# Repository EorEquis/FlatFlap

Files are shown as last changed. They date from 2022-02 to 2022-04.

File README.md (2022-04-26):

## What 
	A "Cover/Calibrator".  Features a motorized telescope cover, and optional calibrator 
	(light/led/EL panel) controller.

## Who
	Created By:  eorequis@stuffupthere.com

## When
	Last modified:  2022-02-11

## Current State
	V2 Arduino Firmware
		The basic syntax of the serial connection protocol is :
		c00n# : c = command ([P]ing, [C]over, [L]ight) and n is typically a value mapped to ASCOM enums
		for cover and calibrator.
		
		List of common commands:
		P000#
		Ping to check if board is connected. Returns P999* when successful.
		
		C001#
		Close the cover. Returns C020* if closing, and C011* if already closed.
		
		C003#
		Open the cover. Returns C020* if opening, and C031* if already opened.
		
		L001#
		Turn off light. Returns L010* if it switch off, and L011* if already off.
		S001* or S003* means the light is not configured.
		
		L003#
		Turn On light. Returns L030* if it switched on, and L031* if already on.
		S001* or S003* means the light is not configured.
		
		S000#
		Check staus. Returns S0[light status][cover status]*
		Light status can be 0 (not configured), 1 (off), or 3 (on).
		Cover status can be 1 (closed), 2 (moving), or 3 (open).
		Any other numbers indicate an error.
		
	ASCOM Driver Options. Use only one, you cannot connect to both at the same time. Only CoverCalibrator can
	control both the cover and light.
	
	ASCOM Switch Driver updated to V2 protocol 
		The ASCOM.ScopeCover.Switch can function as a switch driver to control only the cover.  Useful
		if you don't want/need the complexity of a calibration light, and also allows greater flexibility 
		with various clients/sequencing strategies.
		
		Download ScopeCover Setup.exe to install this driver.
	
	ASCOM CoverCalibrator Driver
		The ASCOM.FlatFlap.CoverCalibrator driver can be used with either a cover only (the light 
		functionality will still present in the client, but will do nothing) or with some sort of 
		switchable light source.  (My own device is a small EL sheet and 12V DC inverter, 
		controlled by a small relay). 
		
		Download FlatFlap Setup.exe to install this driver.
	
## Tested With
	Servos: 
		HiTec HS-635HB - https://servodatabase.com/servo/hitec/hs-635hb
		Aero Sport CS-28R - They're so old there is no URL.
		SG-90 Micro Servos.  There's dozens of various brands with the same model number.  Any should work.
			
	Arduino Boards:
		Gikfun Arduino Nano Clone - https://www.amazon.com/gp/product/B00SGMEH7G
		Arduino Uno - https://www.amazon.com/gp/product/B008GRTSV6/
		ELEGOO UNO R3 Board - https://www.amazon.com/ELEGOO-Board-ATmega328P-ATMEGA16U2-Compliant/dp/B01EWOE0UU
		ELEGOO MEGA R3 Clone - https://www.amazon.com/gp/product/B01H4ZLZLQ/
		Some Uno clone I can't even find a name of or link to.
	
	Relays:
		ARCELI KY-019 5V One Channel Relay - https://www.amazon.com/gp/product/B07BVXT1ZK/
		
	Calibrator Lights
		Adafruit EL Panel - https://www.adafruit.com/product/625 
		Adafruit 12V EL inverter - https://www.adafruit.com/product/448
		
	Software:
		Sequence Generator Pro 
			4.0.0.700 64 Bit
			4.1.0.741 64 Bit
		N.I.N.A 
			V2.0 BETA 019 
			V2.0 BETA 045
			V2.0 BETA 049
			V2.0 RC001

## Usage Notes
	V2 Arduino Firmware configuration
		Compile and upload the firmware with the Arduino IDE. Make sure to choose
		the correct board, processor, and port under the "Tools" menu. Everything
		you need to change is in "Config.h"
		
		DEBUG cannot be used with the ASCOM driver. It gives aditional responses
		in the serial monitor, that the driver cannot understand.
		
		SERVOREVERSE is needed if the cover closes when you try to open it and vice
		versa. You may have to switch the closedPos and openPos values, since this
		option only changes direction.
		
		RELAYLOW is needed if the light turns on when you try to turn it off and
		vice versa.
		
		CALIBRATOR needs to be defined if you are using a light panel. Comment it
		out if you only want to use the scope cover.
		
		closedPos may need to be adjusted to keep from trying to force the servo
		past the fully closed position. If the servo makes noise when closed,
		adjust until it is sealed but quiet.
		
		openPos can be adjusted if you want the cover to open a different amount.
		
		servoPin can be changed if you want to use a differnt pin for the servo.
		
		lightPin can be changed if you want to use a different pin for the relay.
		
		servodelay controls the speed the servo moves.
	
	Arduino resets on serial connection. (Ignore if using ScopeCover only)
		The ASCOM driver code by default is compiled with a 2000ms wait when
		connecting. This will give the Arduino time to reset before use.
		
		Optionally, you can stop it from resetting by adding a 10uf capacitor to
		the arduino between GND and RST. You can then remove the wait(2000) line
		in the Connected(Set) from the ASCOM driver code, recompile and resintall
		the driver.
		
	SGP Switch Handling
		Sequence Generator Pro (As of v4 anyway) handles switches...strangely.  
		After initial install, the first time you run SGP, it will claim to 
		find and connect to the switch, but probably won't actually connect.  
		(Unless your arduino is COM1...unlikely)
		
		To "solve" this either go to SGP's Switches tab in SGP Control Panel, and 
		change the switch's setting to reflect the correct COM Port, then stop and 
		restart SGP.

		OR
		
		Before launching SGP, open any other client program that doesn't try to 
		auto-connect every switch driver on your system, and configure the ScopeCover 
		switch to the correct COM port before connecting to it.  Disconnect and exit 
		gracefully, and the setting will be retained in the device profile.
		
		OR
		
		Before running SGP after switch installation, launch ASCOM Profile Explorer, 
		find "ASCOM.ScopeCover.Switch" in the "Switch Drivers" section on the left.  
		Click "ASCOM.ScopeCover.Switch", and then in the right pane, add a new Value
		called "COM Port" (Note the space) with Data of "COMn" (Note the lack of a 
		space) where n is your device's com port.


		
		You should also note : If you install the Switch Driver, and later the CC 
		driver, using the same arduino, SGP will retain the previous switch driver's 
		config, and auto-connect to that COM port, thus causing connection attempts to 
		the new CC driver to fail, Access to COM Port Denied.

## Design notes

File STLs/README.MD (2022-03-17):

## Servo Mounts
	Each servo mount is named "Mount Type NNNmm".
	Type = Type of servo.  Standard, Micro, etc.
	NNNmm = The approximate DIAMETER of the arc the "feet" sit on.  Select or modify 
		(And share if you do!) the mount with the correct servo type and OUTER diameter
		of your scope tube.

## Scope Caps
	The one-piece "Full Scope Cover" comes from the original Thing at 
		https://www.thingiverse.com/thing:2307397. It has a diameter of approximately 
		115mm.  It can be resized as needed, but bear in mind that rescaling will
		also rescale the servo mount hole.
	The two-piece, "arm" and "lid" are a simpler design requiring no supports, but 
		they do need to be glued together. It has a diameter of approximately 100mm, 
		and should be considerably easier to resize. Just remember to adjust the 
		width of the slot appropriately.
		
## Enclosures
	Nano Enclosure is a modified version of https://www.thingiverse.com/thing:5238660
		The indent for the USB plug has been made deeper for more secure connections,
		and the lid	tweaked for a slightly better fit.

## CAD Files
	Where I have them, I have uploaded SketchUp files, created in Sketchup Make 2017.
	
	If you modify/create your own files for use on a particular scope/lens/etc, please
	share whatever STLs and/or CAD files you have. :)

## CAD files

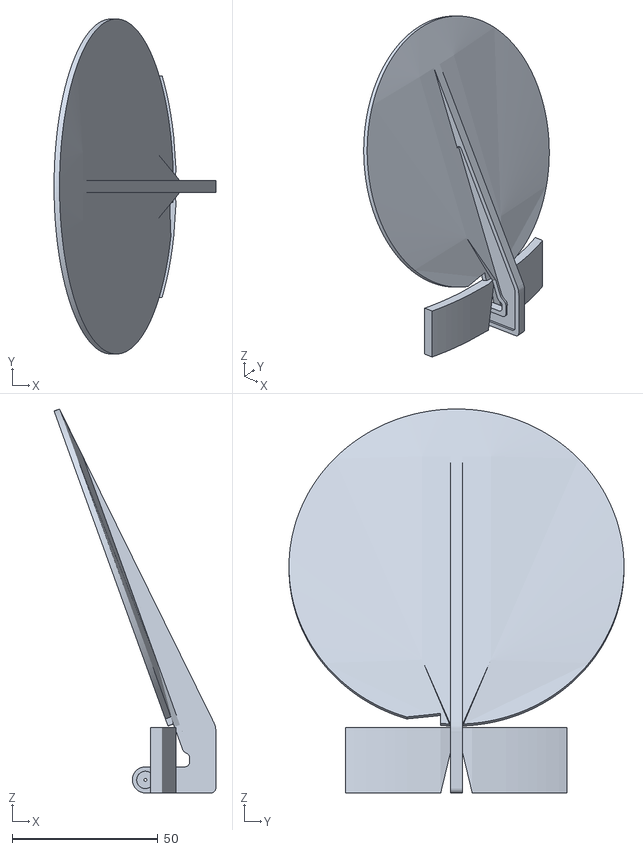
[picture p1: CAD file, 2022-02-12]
STLs/Full ScopeCover-Supported.stl
55.6 x 115.0 x 131.8

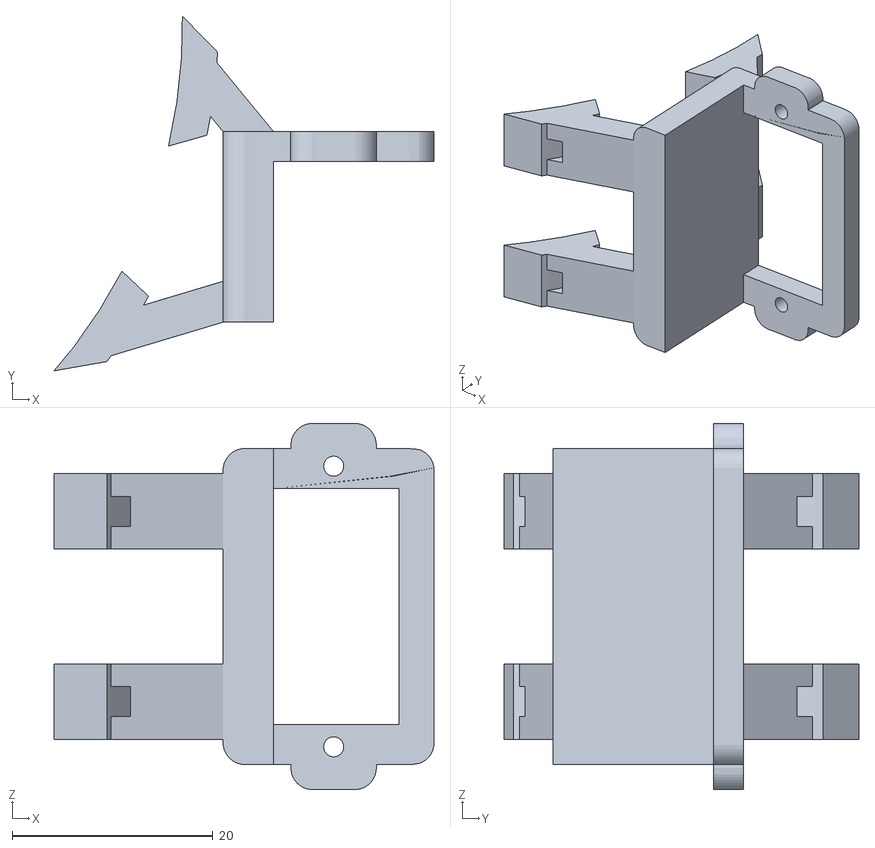
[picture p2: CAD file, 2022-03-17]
STLs/Mount Micro Servo 110mm.stl
37.9 x 35.3 x 36.5

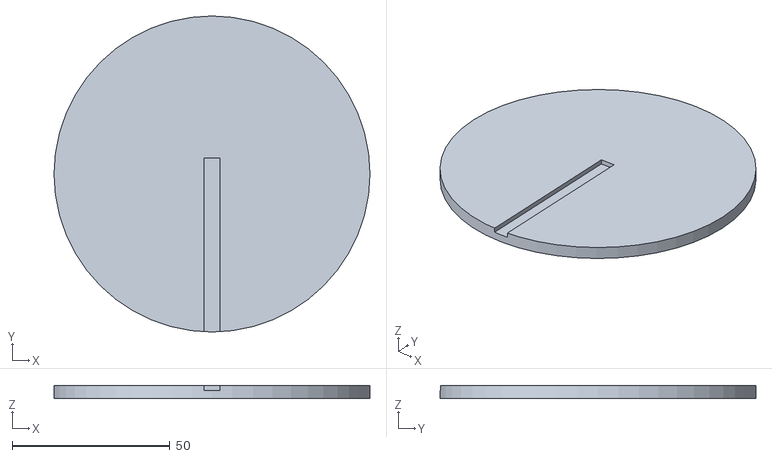
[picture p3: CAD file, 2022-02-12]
STLs/Lidv2.stl
100.0 x 100.0 x 4.00

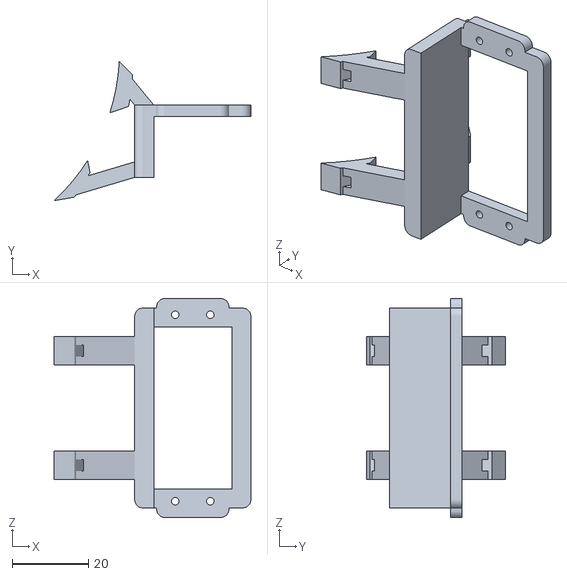
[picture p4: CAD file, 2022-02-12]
STLs/Mount Std Servo 100mm.stl
51.7 x 36.6 x 57.5

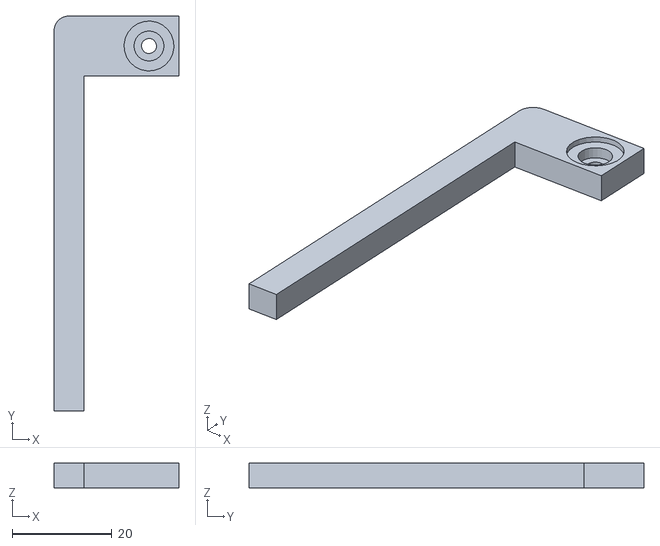
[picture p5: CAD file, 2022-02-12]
STLs/Armv2.stl
25.0 x 79.0 x 5.00

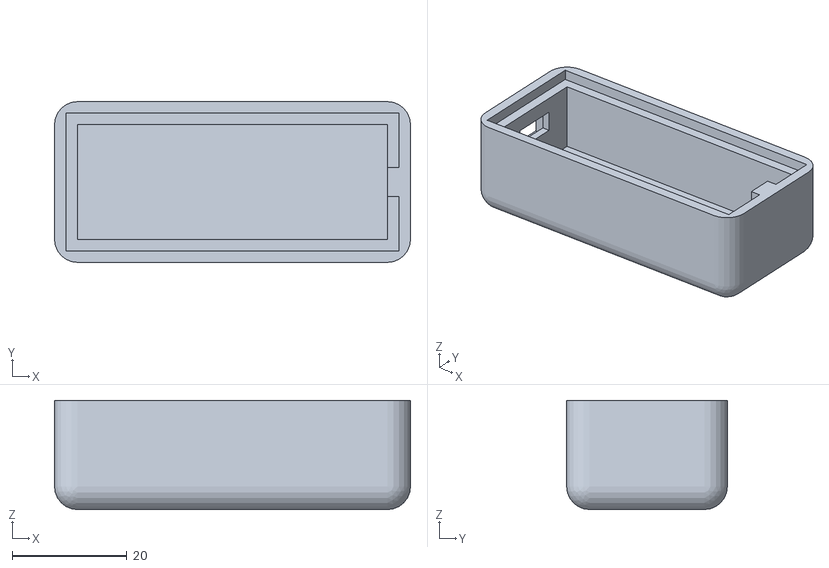
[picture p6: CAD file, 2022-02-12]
STLs/nano enclosure box v3.stl
62.0 x 28.0 x 19.0

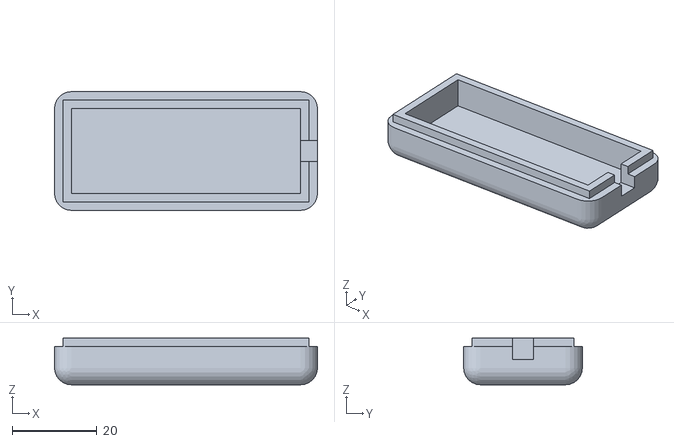
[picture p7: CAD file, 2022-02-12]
STLs/nano enclosure lid v3.stl
62.0 x 28.0 x 11.0

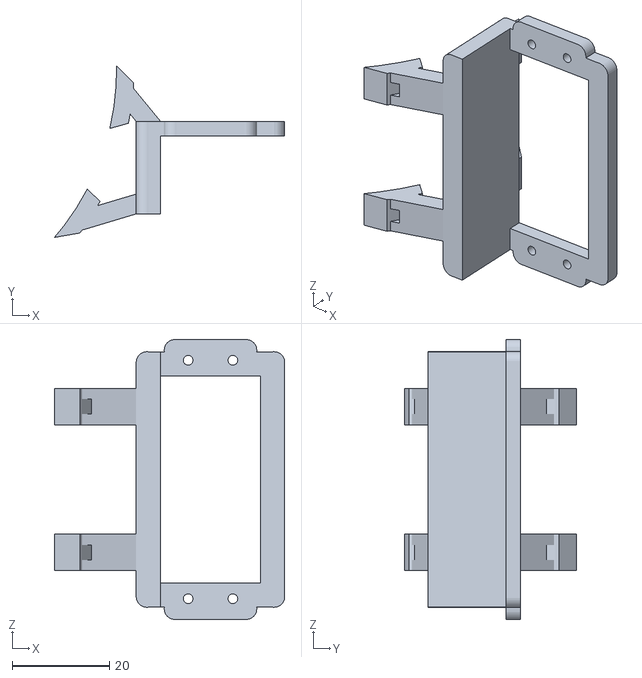
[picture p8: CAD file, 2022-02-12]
STLs/Mount Std Servo 120mm.stl
47.4 x 35.3 x 57.5

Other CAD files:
STLs/Cover Arm and Lid v2.skp
STLs/Mount Std Servo 100mm.skp
STLs/nano enclosure.skp

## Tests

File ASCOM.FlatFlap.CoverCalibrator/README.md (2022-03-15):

## What 
	ASCOM Cover Calibrator driver for use with Flat Flap.

## Who
	Created By:  eorequis@stuffupthere.com

## When
	Last modified:  2022-02-11

## Current State
	Conformance passed
	
## Tested With
	Software:
		Sequence Generator Pro 
			4.0.0.700 64 Bit
			4.1.0.741 64 Bit
		N.I.N.A 
			V2.0 BETA 019 
			V2.0 BETA 045
			V2.0 BETA 049

## Usage Notes
	Arduino resets on serial connection.
		You can handle this 1 of 2 ways.  
		
		Either retain the 2000ms wait in the Connected(Set)
		of the ASCOM driver code (it is there by default and both setups include drivers
		compiled with this option)
		
		OR
		
		Add a 10uf capacitor to the arduino between GND and RST, remove the wait(2000) 
		line from the driver code, recompile and resintall the driver.
		
	SGP Switch Handling
		If you install the Switch Driver, and later the CC driver, using the same arduino, SGP
		will retain the previous switch driver's config, and auto-connect to that COM port, thus causing connection
		attempts to the new CC driver to fail, Access to COM Port Denied.

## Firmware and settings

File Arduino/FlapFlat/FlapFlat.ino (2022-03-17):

/*
  What: 
    FlapFlat : A motorized scope cover and flat panel in one

  Who:
    Created By:  eorequis@stuffupthere.com

  History:
    2022-02-09  : Initial v 0.1, simple "open"/"clos" string commands, scope cover only
    2022-02-10  : V2 comms protocol, char handling
    2022-02-10  : Addition of light control, debugging/improving V2 protocol, mirroring ASCOm CoverCalibrator enums for cover and light, debug char handling
    2022-02-12  : Return "NotPresent" value for calibrator if light is not present, based on #define set by user before upload
    2022-03-14  : Happy Pi day.  Force lightPin LOW on setup, to try to troubleshoot strange behaviour for another user.  not a bad idea either way.
    2022-03-15  : Add options for relays that expect LOW t be turned on, add comments/testing results.
    2022-03-16  : Remove hardcoded start position for servo when powered up.  Move user selectable options to their own config file.  Add toggle for servo direction
    2022-03-16  : Clean up these comments, no change to functionality

  Stuff you should do before uploading:
    * Check out Globals.h  There are several #define at the top with decisions you need to make.
    * Make sure you know if your relay expects LOW or HIGH to be turned on, and make the appropriate selection in Globals.h

  Notes:
    Be sure to check configurable options in Config.h
    
*/

#include <Servo.h>
#include "Globals.h"
#include "Config.h"


void setup() {
  // initialize the serial communication:
  Serial.begin(9600);
  // Set servo initial position closed, attach servo
  currentpos = closedPos;
  myservo.write(currentpos);
  myservo.attach(servoPin);

  #ifdef CALIBRATOR
    lightStatus = CALIBRATOROFF;
  #endif

  #ifdef RELAYLOW
    relayOn = 0;
    relayOff = 1;
  #endif    

  #ifdef SERVOREVERSE
    servoDirection = -1;
  #endif    

  pinMode(lightPin,OUTPUT);
  digitalWrite(lightPin, relayOff);

}

void loop() {
  handleSerial();
  handleServo();
}

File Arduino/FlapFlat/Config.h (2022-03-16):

// #define DEBUG              // Uncomment to allow debug printout to serial

// #define SERVOREVERSE       // Uncomment this to reverse the direction the servo moves, in case you have some fancy left handed Lithuanian servo

// #define RELAYLOW           // Uncomment this line if your relay turns on with the signal pin driven LOW

#define CALIBRATOR            // Comment this line to return "NotPresent" to ASCOM for light/calibrator

int closedPos = 104;          // Change this to achieve a good flat close against the end of the scope tube.

int openPos = 0;              // The servo position for the flap to be open.
                              // USUALLY this is 0, and a move to close (based on the printed servo mount and arrangement)
                              // is positive, so you start at 0, mount the to the servo at a position that represents "Open"
                              // and tweak closedPos for a good fit.  However, if your servo runs the other way
                              // or you've engineered your own mount, you may want to uncomment SERVOREVERSE above, and
                              // flip this logic.

int servoPin = 5;             // The pin the data line of the servo is attached to.

int lightPin = 9;             // The pin the EL panel's relay is attached to.

int servodelay = 15;          // ms to wait after a servo move of 1 degree.  Higher numbers slow the opening/closing speed                                

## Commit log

2021-03-13 Basic framework : Much swiped from Jared Wellman's work
2021-03-13 Handle motor and shutter states in event of unexpected shutdown
2021-03-19 Modify to use relay to turn EL panel on/off
2022-02-12 Migrate Scope Cover to FlatFlap Repo
    [ScopeCover-Supported.stl, StandardServoMount.stl, nano_enclosure2.stl]
2022-02-12 Change enclosure link
2022-02-12 Add new enclosure files
    [nano enclosure box v3.stl, nano enclosure lid v3.stl, nano_enclosure2.stl]
2022-02-12 Add #define for calibrator
    #ifdef CALIBRATOR now allows protocol to return NotPresent status to ASCOM if not defined.
2022-02-12 Add newer STLs
    [100mmServoMount.stl, FF_Armv2.stl, FF_Lidv2.stl]
2022-03-15 Handle LOW relays, update READMEs
2022-03-16 Remove HC servo pos on powerup, Options to config. Toggle servo dir
    Remove hardcoded start position for servo when powered up. Move user selectable options to their own config file. Add toggle for servo direction
2022-03-17 Clean up STL names, improve readme, edit INO comments
    [Armv2.stl, Full ScopeCover-Supported.stl, Lidv2.stl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]
2022-03-17 Add sketchup files, update README
    [Cover Arm and Lid v2.skp, Mount Std Servo 100mm.skp, nano enclosure.skp]
